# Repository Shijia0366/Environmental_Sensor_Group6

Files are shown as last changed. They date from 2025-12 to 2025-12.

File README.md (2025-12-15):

# Environmental Sensor Project - Group 6

This repository contains the complete design resources, source code, and measurement data for the Environmental Sensor project.

## Group Members
* Arno Liu
* Chengyu Yang
* Shijia Liu
* Zheyang Zheng

## Repository Structure

### 📂 Code
This folder contains the firmware source code. It includes two distinct sets of code:
* **Autonomous_Nodes_Environmental_Sensors:** Code developed for our self-fabricated sensor modules.
* **Commercial_Sensor:** Code tailored for the sensor provided by the department.

### 📂 Data
This folder contains real-world environmental data collected during field testing, organized chronologically by timestamp.
* **Calibration Note:** Please note that the first two data files contain **uncalibrated** raw data. All subsequent files contain **calibrated** data.
* **Note on ACC/PPG:** The `acc''ppg' dataset may show no readings due to system instability during the initial recording phase. However, the module was fully functional and successfully demonstrated during the final demo day.

### 📂 Enclosure
This folder stores all SolidWorks CAD files for the device housing.
* **Final Assembly:** The finalized 3D model is located in the file: `Enclosure design 3D Group 6 Final.SLDASM`.

### 📂 PCB
Contains the complete PCB design files used for the project.

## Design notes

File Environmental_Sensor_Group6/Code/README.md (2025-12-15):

#  MSc Sensor Systems Lab: Environmental Sensor Project - Group 6

##  Project Overview

* **Autonomous_Nodes_Environmental_Sensors:** Developed for the custom PCB (Task 1), utilizes the MAX30102 (PPG) for health data, the accelerometer is disabled due to hardware failure. Together with all environmental sensors.
* **Commercial_Sensor:** Developed for the department sensors nodes, utilizes the Pulse Sensor Amped (Green Light only) to capture Signal/BPM and the MPU-6050 (ACC) for motion data.
Both implementations are fully compatible with the Task 2 Environmental Sensor code and successfully perform environmental data acquisition.

## Group Members
| **Arno Liu** | |
| **Chengyu Yang** | |
| **Shijia Liu** | |
| **Zheyang Zheng** | |

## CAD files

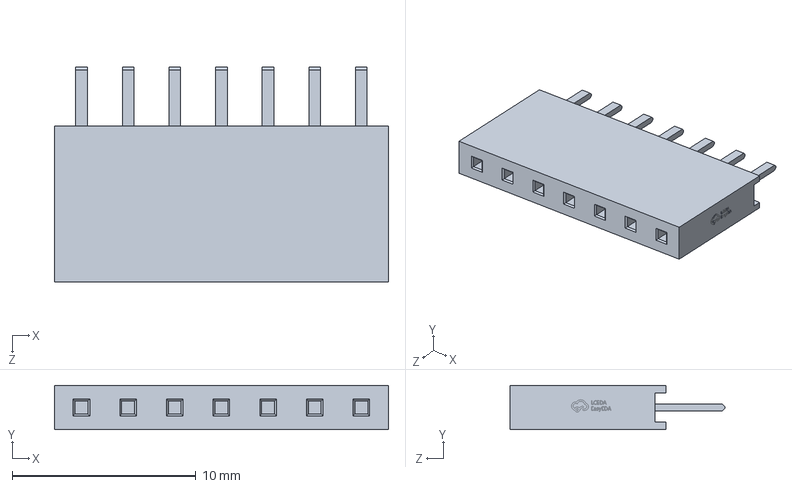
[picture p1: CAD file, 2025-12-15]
Environmental_Sensor_Group6/Enclosure/BME688~HDR-TH_7P-P2.54-V-F~HDR-TH_7P-P2.54-F-LI-1X7P~KTJj.SLDASM
18.2 x 2.40 x 11.7 mm

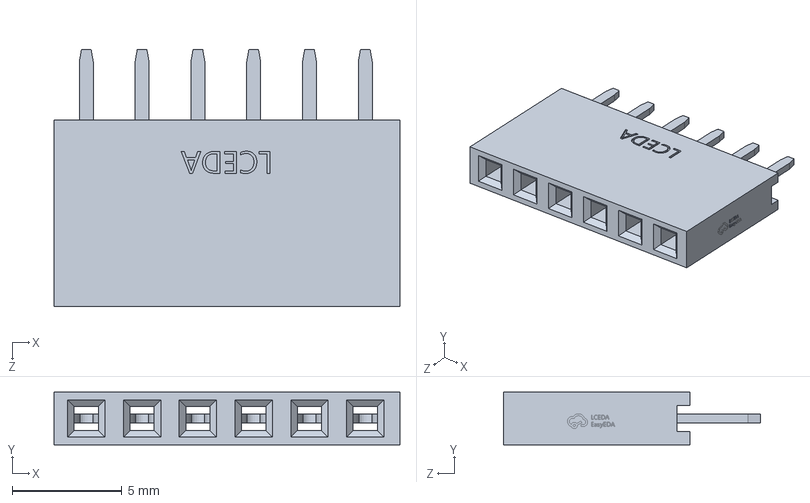
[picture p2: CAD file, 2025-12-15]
Environmental_Sensor_Group6/Enclosure/GPS1~HDR-TH_6P-P2.54-V-F~HDR-TH_6P-P2.54-V-F~KTJj.SLDASM
15.7 x 2.40 x 11.7 mm

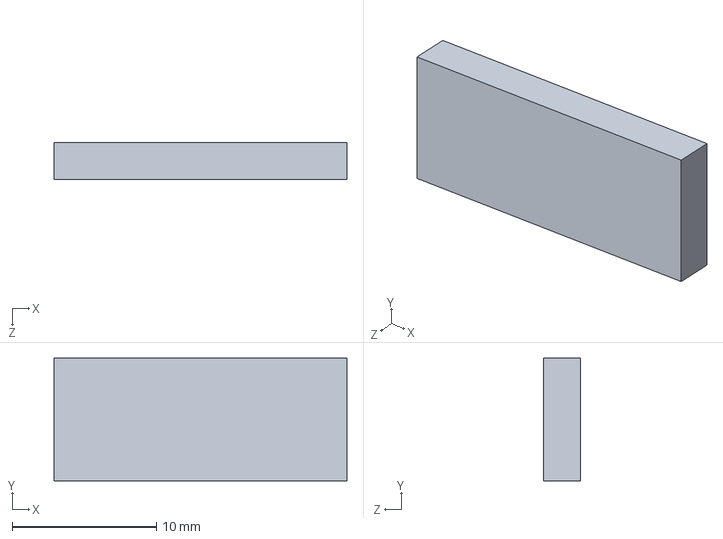
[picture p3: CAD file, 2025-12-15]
Environmental_Sensor_Group6/Enclosure/sd Socket.SLDPRT
20.3 x 8.50 x 2.54 mm

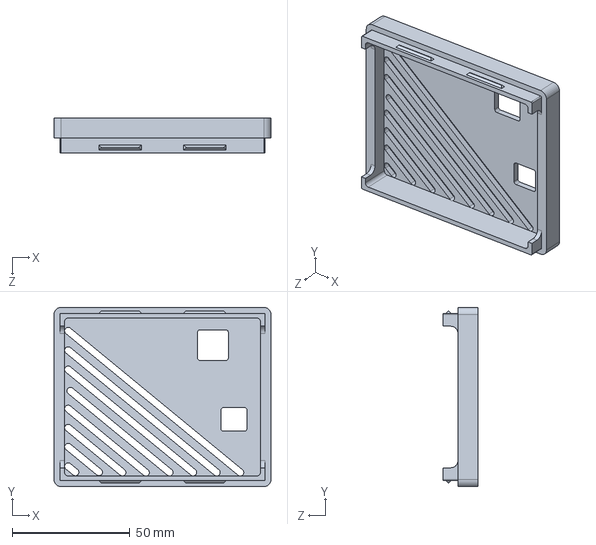
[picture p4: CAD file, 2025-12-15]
Environmental_Sensor_Group6/Enclosure/Cover.SLDPRT
92.0 x 76.0 x 14.8 mm

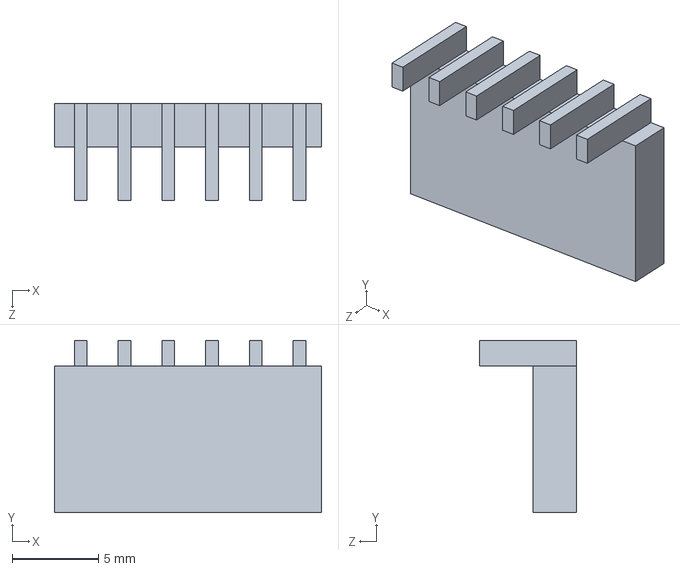
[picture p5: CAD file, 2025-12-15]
Environmental_Sensor_Group6/Enclosure/Right-Angle Female connector tof.SLDPRT
15.5 x 10.0 x 5.60 mm

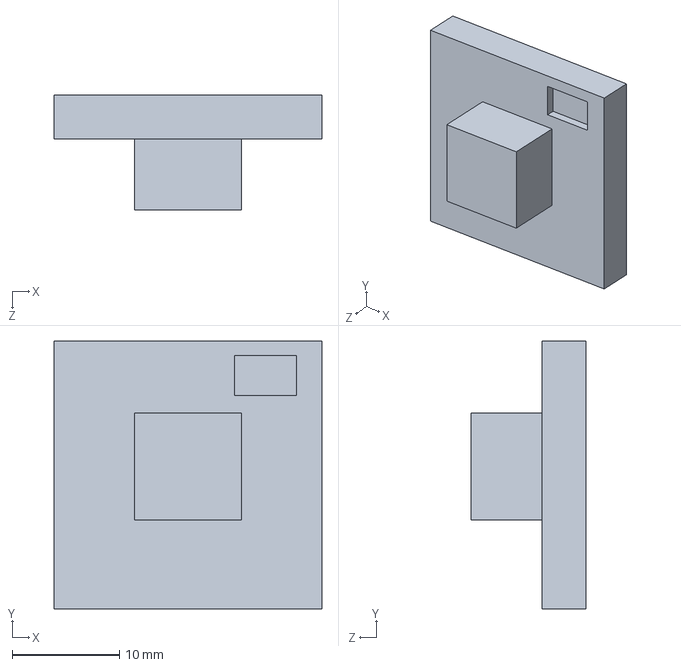
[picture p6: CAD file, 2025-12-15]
Environmental_Sensor_Group6/Enclosure/gps.SLDPRT
25.0 x 25.0 x 10.7 mm

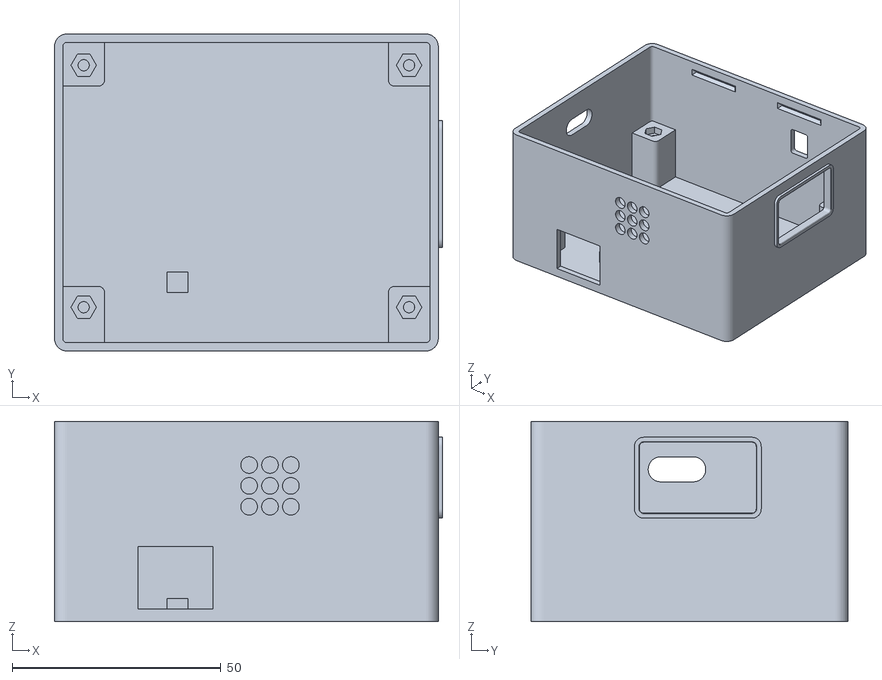
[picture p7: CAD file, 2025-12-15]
Environmental_Sensor_Group6/Enclosure/Enclosure design 3D Group 6 - Enclosure-1.STL
93.0 x 76.0 x 48.0

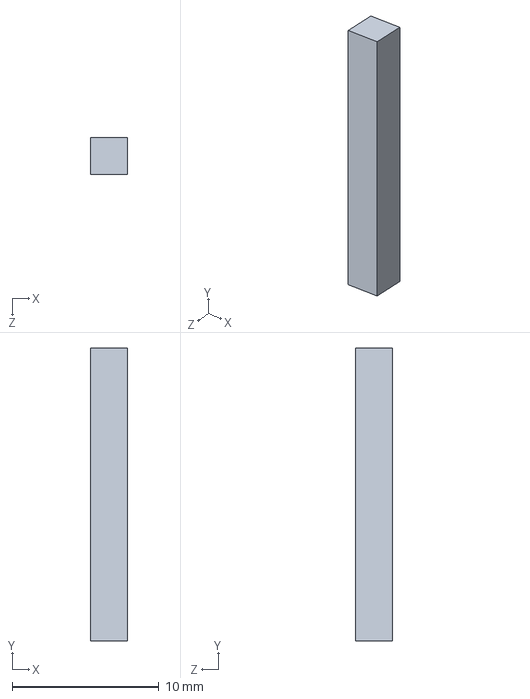
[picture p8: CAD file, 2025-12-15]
Environmental_Sensor_Group6/Enclosure/sd.SLDPRT
2.50 x 20.0 x 2.50 mm

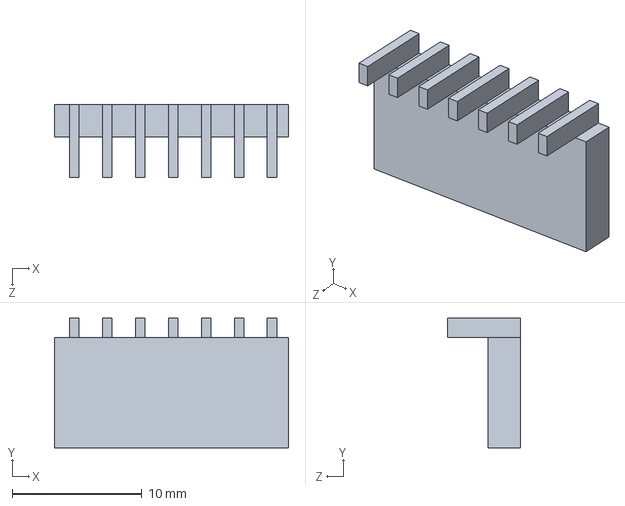
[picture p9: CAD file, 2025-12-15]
Environmental_Sensor_Group6/Enclosure/Right-Angle Female connector bme.SLDPRT
18.0 x 10.0 x 5.60 mm

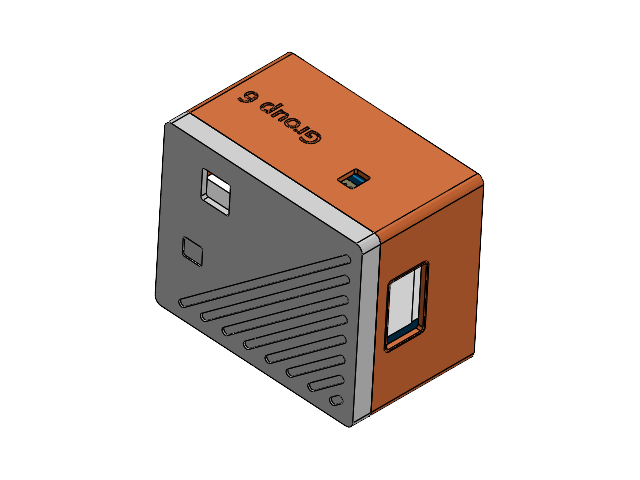
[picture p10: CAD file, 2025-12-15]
Environmental_Sensor_Group6/Enclosure/Environmental sensor pcb.SLDASM
HDR-TH_7P-P2.54-V-F~HDR-TH_7P-P2.54-F-LI-1X7P~KTJj x 2
HDR-TH_12P-P2.54-V-F~HDR-TH_12P-P2.54-F-LI-1X12P~KTJj
HDR-TH_6P-P2.54-V-F~HDR-TH_6P-P2.54-V-F~KTJj x 3
HDR-TH_16P-P2.54-V-F-1~HDR2.54-F-LI-1X16P~KTJj
RES-TH_BD2.7-L6.2-P10.20-D0.4~RES-TH_BD2.7-L6.2-P10.20-D0.4~KTJj x 2
Board~KTJj
TopSilkscreen~KTJj
BottomSilkscreen~KTJj
壳子
oled
esp32
弯母座
254.step
盖子
Board.step x 2
10uF.step x 4
AP2112K-3.3.step x 2
10K.step x 8
10K_1.step x 2
BSS138.step x 2
STEMMA_I2C_QT.step x 4
GREEN.step x 2
1N4148.step x 2
BME680.step x 2
弯母座bme
弯母座tof
按钮
gps

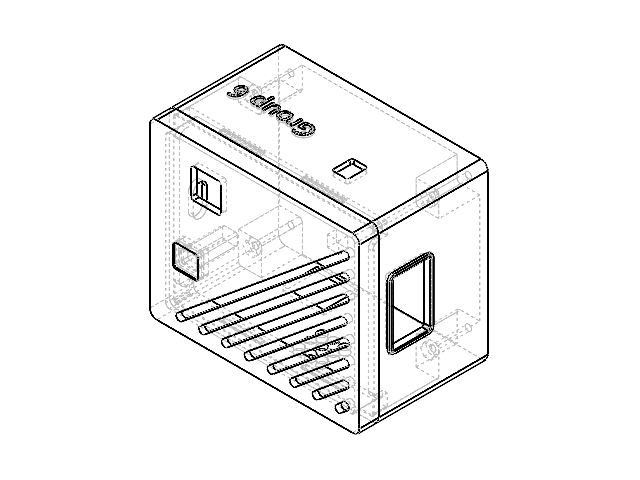
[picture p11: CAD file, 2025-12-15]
Environmental_Sensor_Group6/Enclosure/Enclosure design 3D Group 6 Final.SLDASM
Button
Cover
Enclosure
button fitting component

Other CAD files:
Environmental_Sensor_Group6/Enclosure/4MB Flash 2MB PSRAM~HDR-TH_16P-P2.54-V-F-1~HDR2.54-F-LI-1X16P~KTJj.SLDASM
Environmental_Sensor_Group6/Enclosure/ESP32 S3~HDR-TH_12P-P2.54-V-F~HDR-TH_12P-P2.54-F-LI-1X12P~KTJj.SLDASM
Environmental_Sensor_Group6/Enclosure/R2~RES-TH_BD2.7-L6.2-P10.20-D0.4~RES-TH_BD2.7-L6.2-P10.20-D0.4~KTJj.SLDASM
Environmental_Sensor_Group6/Enclosure/Board~KTJj.SLDPRT
Environmental_Sensor_Group6/Enclosure/Enclosure design 3D Group 6 - Cover-1.STL
Environmental_Sensor_Group6/Enclosure/HDR-TH_6P-P2.54-V-F~HDR-TH_6P-P2.54-V-F~KTJj.SLDPRT
Environmental_Sensor_Group6/Enclosure/HDR-TH_7P-P2.54-V-F~HDR-TH_7P-P2.54-F-LI-1X7P~KTJj.SLDPRT
Environmental_Sensor_Group6/Enclosure/BottomSilkscreen~KTJj.SLDPRT
Environmental_Sensor_Group6/Enclosure/Button.SLDPRT
Environmental_Sensor_Group6/Enclosure/Enclosure design 3D Group 6 - button fitting component-1.STL
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

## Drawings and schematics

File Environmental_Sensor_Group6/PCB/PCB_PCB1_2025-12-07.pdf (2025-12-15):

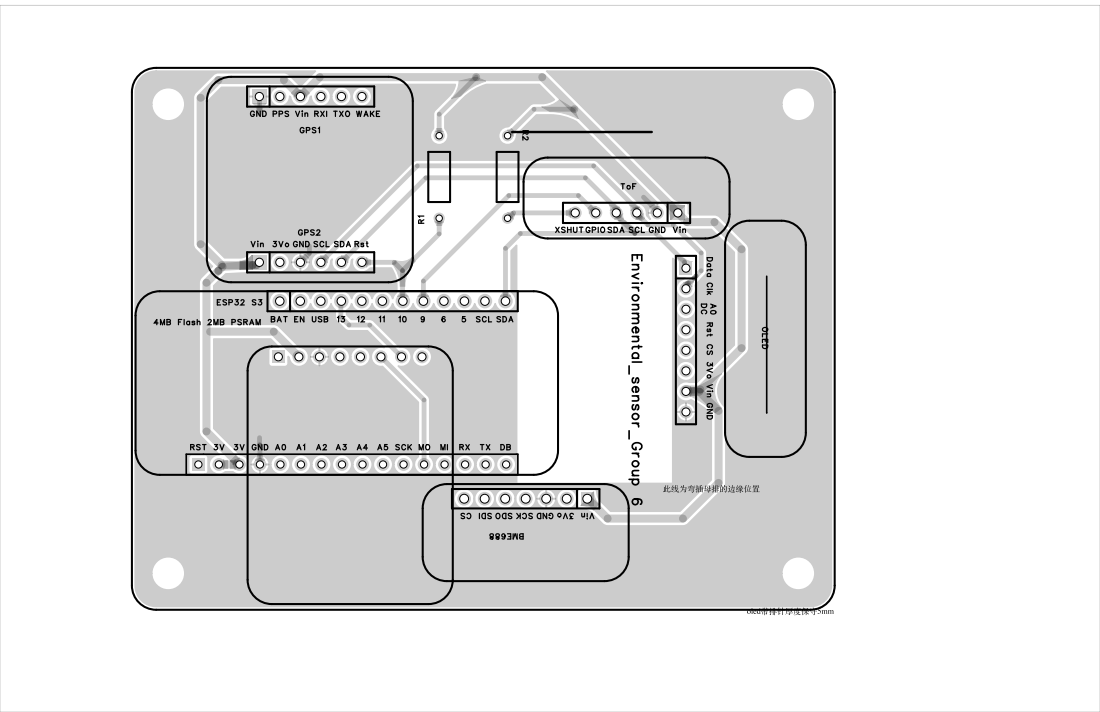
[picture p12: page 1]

GND
PPS Vin RXI TXO WAKE
GPS1

XSHUTGPIOSDA SCL GND Vin

Data Clk DCA0 Rst CS 3Vo Vin GND

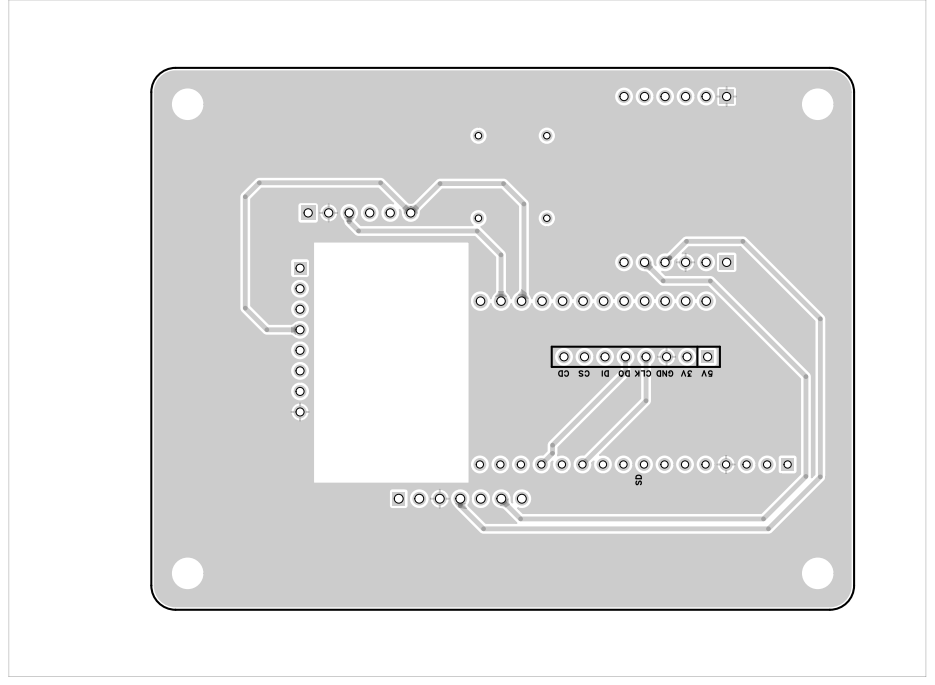
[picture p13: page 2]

CD CS DI DO CLK GND 3V 5V SD

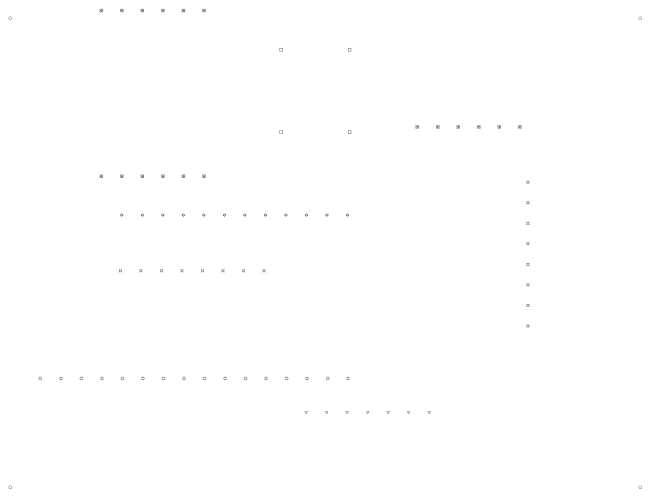
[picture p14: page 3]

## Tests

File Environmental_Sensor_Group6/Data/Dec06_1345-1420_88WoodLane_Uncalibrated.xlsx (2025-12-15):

timestamp_ms | temp_c | hum_pct | press_hpa | gas_ohm | AQI | dist_mm | speed | lat | lon | alt_m | fix | acc_x | acc_y | acc_z | ppg_red | ppg_ir
5046 | 16.19 | 59.7 | 996.5 | 7893 | 0 | 25 | nan | nan | nan | nan | 0 | nan | nan | nan | 0 | 0
10049 | 16.13 | 58.4 | 996.6 | 19565 | 0 | 31 | nan | nan | nan | nan | 0 | nan | nan | nan | 0 | 0
15031 | 16.27 | 57.5 | 996.6 | 29602 | 0 | 26 | nan | nan | nan | nan | 0 | nan | nan | nan | 0 | 0
20013 | 16.35 | 56.8 | 996.6 | 38988 | 0 | 25 | nan | nan | nan | nan | 0 | nan | nan | nan | 0 | 0
25006 | 16.37 | 56.1 | 996.6 | 48448 | 0 | 35 | nan | nan | nan | nan | 0 | nan | nan | nan | 0 | 0
30003 | 16.23 | 55.6 | 996.6 | 55077 | 0 | 37 | nan | nan | nan | nan | 0 | nan | nan | nan | 0 | 0
35007 | 16.22 | 55.3 | 996.6 | 61068 | 0 | 37 | nan | nan | nan | nan | 0 | nan | nan | nan | 0 | 0
40013 | 16.14 | 55.1 | 996.6 | 67121 | 0 | 37 | nan | nan | nan | nan | 0 | nan | nan | nan | 0 | 0
45018 | 16.06 | 55 | 996.6 | 72051 | 0 | 37 | nan | nan | nan | nan | 0 | nan | nan | nan | 0 | 0
50019 | 16.16 | 55 | 996.6 | 76099 | 0 | 38 | nan | nan | nan | nan | 0 | nan | nan | nan | 0 | 0
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

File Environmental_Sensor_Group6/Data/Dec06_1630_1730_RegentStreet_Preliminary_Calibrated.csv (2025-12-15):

timestamp_ms | temp_c | hum_pct | press_hpa | gas_ohm | AQI | dist_mm | speed | lat | lon | alt_m | fix | acc_x | acc_y | acc_z | ppg_red | ppg_ir
5053 | 19.59 | 54 | 998.2 | 5684 | 10 | 52 | nan | nan | nan | nan | 0 | nan | nan | nan | 0 | 0
10057 | 19.38 | 52.6 | 998.2 | 12688 | 10 | 19 | nan | nan | nan | nan | 0 | nan | nan | nan | 0 | 0
15041 | 19.34 | 51.8 | 998.3 | 19565 | 8 | 9 | nan | nan | nan | nan | 0 | nan | nan | nan | 0 | 0
20020 | 19.13 | 51.6 | 998.2 | 24975 | 7 | 41 | nan | nan | nan | nan | 0 | nan | nan | nan | 0 | 0
25038 | 19.18 | 51.9 | 998.2 | 31364 | 6 | 19 | nan | nan | nan | nan | 0 | nan | nan | nan | 0 | 0
30039 | 19.16 | 51.7 | 998.3 | 36488 | 5 | 14 | nan | nan | nan | nan | 0 | nan | nan | nan | 0 | 0
35045 | 19.11 | 51.5 | 998.3 | 40855 | 5 | 21 | nan | nan | nan | nan | 0 | nan | nan | nan | 0 | 0
40050 | 19.23 | 51.5 | 998.3 | 44614 | 5 | 10 | nan | nan | nan | nan | 0 | nan | nan | nan | 0 | 0
45055 | 19.21 | 51.3 | 998.3 | 49459 | 4 | 13 | nan | nan | nan | nan | 0 | nan | nan | nan | 0 | 0
50019 | 19.23 | 51.4 | 998.4 | 52117 | 4 | 45 | nan | nan | nan | nan | 0 | nan | nan | nan | 0 | 0
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

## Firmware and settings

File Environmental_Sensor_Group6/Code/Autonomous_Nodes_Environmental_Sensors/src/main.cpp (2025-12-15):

#include <Arduino.h>
#include "config.h"

// Diagnostic Mode
#if DIAG_MODE
void diag_setup();
void diag_loop();
void setup(){ diag_setup(); }
void loop() { diag_loop();  }

// Normal Application Mode
#else
void app_setup();
void app_loop();
void setup(){ app_setup(); }
void loop() { app_loop();  }
#endif

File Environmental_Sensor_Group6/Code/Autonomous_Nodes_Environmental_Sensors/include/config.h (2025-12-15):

#pragma once

/************ I2C  ************/
#define I2C_SDA_PIN            -1        
#define I2C_SCL_PIN            -1
#define I2C_FREQUENCY          400000    

// STEMMA/QT Power switch
#define PIN_I2C_POWER          7
#define I2C_POWER_DELAY_MS     50         
#define I2C_BUS_SETTLE_MS      100       

/************ SPI ************/

#define SPI_SCK_PIN            -1        
#define SPI_MISO_PIN           -1        
#define SPI_MOSI_PIN           -1        

/************ SD Card (SPI) ************/
#define SD_CS                  13        
#define SD_INIT_FREQ_HZ        400000    
#define SD_WORK_FREQ_HZ        20000000  
#define SD_POWER_DELAY_MS      10        

#define SD_CD_PIN              -1        
#define SD_CD_ACTIVE_LOW       1         
#define SD_CD_DEBOUNCE_MS      20

/************ Device I2C Addresses ************/
#define ToF_ADDR               0x29
#define GPS_ADDR               0x10      // according to your GPS module's actual address
#define BME_ADDR               0x77
#define OLED_ADDR              0x3D

/************ Device Control Pins ************/
#define OLED_RESET             5        // OLED RST
// #define OLED_RESET             -1        
#define TOF_XSHUT_PIN          5        
// #define TOF_XSHUT_PIN          -1       

#define TOF_INT_PIN     9      


/************ App Settings ************/
#define LOG_INTERVAL_MS        10      
#define CSV_FILE_PATH          "/logs/data.csv"
#define CSV_HEADER             "timestamp_ms,temp_c,hum_pct,press_hpa,gas_ohm,AQI,dist_mm,speed,lat,lon,alt_m,fix,acc_x,acc_y,acc_z,HR,SPO2"

#define DIAG_MODE 0   //1 = Enter diagnostic mode; 0 = Normal app mode

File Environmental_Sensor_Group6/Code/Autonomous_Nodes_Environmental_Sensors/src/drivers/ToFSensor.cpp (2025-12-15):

#include "ToFSensor.h"

Status ToFSensor::begin(TwoWire& w, uint8_t i2cAddr, int8_t xshutPin, int8_t intPin) {
  addr_  = i2cAddr;
  xshut_ = xshutPin;
  intPin_= intPin;

  // XSHUT Hardware Reset (Optional)
  hwReset_();

  // Dynamically create VL53L4CX, passing TwoWire and XSHUT
  if (tof_) { delete tof_; tof_ = nullptr; }
  tof_ = new VL53L4CX(&w, xshut_);

  // Power on sequence (as per standard flow)
  tof_->begin();
  tof_->VL53L4CX_Off();

  // Initialize Sensor with address
  if (tof_->InitSensor(addr_) != 0) {
    ready_ = false;
    return Status::Err("ToF InitSensor failed");
  }

  // Configure ranging parameters and mode
  if (!configureRanging_().ok) {
    ready_ = false;
    return Status::Err("ToF configure failed");
  }

  // Interrupt Setup: GPIO1 output data ready (Low Active)
  if (intPin_ >= 0) {
    // pinMode(intPin_, INPUT_PULLUP);   // Common default
    pinMode(intPin_, INPUT); 
    intFired_ = false;
    attachInterruptArg(intPin_, &ToFSensor::isrThunk_, this, FALLING);
  }

  ready_ = true;
  return Status::Ok();
}

Status ToFSensor::configureRanging_() {
  int st = 0;

  // Distance Mode: SHORT / MEDIUM / LONG
  st |= tof_->VL53L4CX_SetDistanceMode(VL53L4CX_DISTANCEMODE_MEDIUM);
  if (st) return Status::Err("ToF set distance mode failed");

  // Timing Budget (us)
  st |= tof_->VL53L4CX_SetMeasurementTimingBudgetMicroSeconds(TOF_TIMING_BUDGET_MS * 1000UL);
  if (st) return Status::Err("ToF set timing budget failed");

  // Continuous Ranging
  st |= tof_->VL53L4CX_StartMeasurement();
  if (st) return Status::Err("ToF start measurement failed");

  return Status::Ok();
}


void ToFSensor::hwReset_() {
  if (xshut_ < 0) return;
  pinMode(xshut_, OUTPUT);
  digitalWrite(xshut_, LOW);   // Power Off
  delay(2);                    // tRESET >= 1ms
  digitalWrite(xshut_, HIGH);  // Power On
  delay(5);                    // Power stabilization
}

// Interrupt ISR Thunk
void IRAM_ATTR ToFSensor::isrThunk_(void* arg) {
  reinterpret_cast<ToFSensor*>(arg)->onInt_();
}
void IRAM_ATTR ToFSensor::onInt_() {
  intFired_ = true;
}

Status ToFSensor::read(float& dist_mm) {
  if (!ready_) return Status::Err("ToF not initialized");

  // Check Data Ready: Prefer Interrupt flag, then Register polling
  uint32_t t0 = millis();
  while (true) {
    bool ready = false;

    if (intPin_ >= 0) {
      // INT Low or ISR fired means ready
      if (!digitalRead(intPin_) || intFired_) {
        ready = true;
        intFired_ = false; // Consume flag
      }
    } else {
      // Poll ULD data-ready
      uint8_t newReady = 0;
      int st = tof_->VL53L4CX_GetMeasurementDataReady(&newReady);
      if (st == 0 && newReady) ready = true;
    }

    if (ready) break;
    if (millis() - t0 > TOF_TIMEOUT_MS) return Status::Err("ToF timeout");
    
    delay(1); // Avoid busy loop
  }

  // Read Multi-Object Data (Taking object #0)
  VL53L4CX_MultiRangingData_t data;
  int st = tof_->VL53L4CX_GetMultiRangingData(&data);
  if (st != 0 || data.NumberOfObjectsFound < 1) {
    // Clear interrupt and proceed to next frame
    tof_->VL53L4CX_ClearInterruptAndStartMeasurement();
    return Status::Err("ToF invalid frame");
  }

  dist_mm = data.RangeData[0].RangeMilliMeter;

  // Clear interrupt and restart next frame (Crucial for Continuous mode)
  tof_->VL53L4CX_ClearInterruptAndStartMeasurement();

  return Status::Ok();
}

Status ToFSensor::stop() {
  if (!ready_) return Status::Err("ToF not initialized");
  tof_->VL53L4CX_StopMeasurement();
  if (intPin_ >= 0) detachInterrupt(intPin_);
  return Status::Ok();
}

Status ToFSensor::start() {
  if (!ready_) return Status::Err("ToF not initialized");
  if (intPin_ >= 0) {
    intFired_ = false;
    attachInterruptArg(intPin_, &ToFSensor::isrThunk_, this, FALLING);
  }
  int st = tof_->VL53L4CX_StartMeasurement();
  if (st != 0) return Status::Err("ToF restart failed");
  return Status::Ok();
}

// === Forwarding Implementation to match ST Examples ===
int ToFSensor::InitSensor(uint8_t newAddr) {
  if (!tof_) return -1;
  addr_ = newAddr;
  return tof_->InitSensor(addr_);
}

int ToFSensor::VL53L4CX_Off() {
  if (!tof_) return -1;
  tof_->VL53L4CX_Off();
  return 0;
}

int ToFSensor::VL53L4CX_StartMeasurement() {
  if (!tof_) return -1;
  return tof_->VL53L4CX_StartMeasurement();
}

int ToFSensor::VL53L4CX_StopMeasurement() {
  if (!tof_) return -1;
  return tof_->VL53L4CX_StopMeasurement();
}

int ToFSensor::VL53L4CX_ClearInterruptAndStartMeasurement() {
  if (!tof_) return -1;
  return tof_->VL53L4CX_ClearInterruptAndStartMeasurement();
}

int ToFSensor::VL53L4CX_GetMeasurementDataReady(uint8_t* isReady) {
  if (!tof_ || !isReady) return -1;
  return tof_->VL53L4CX_GetMeasurementDataReady(isReady);
}

int ToFSensor::VL53L4CX_GetMultiRangingData(VL53L4CX_MultiRangingData_t* data) {
  if (!tof_ || !data) return -1;
  return tof_->VL53L4CX_GetMultiRangingData(data);
}

// === Common Configuration (Optional) ===
int ToFSensor::VL53L4CX_SetDistanceMode(uint8_t mode) {
  if (!tof_) return -1;
  return tof_->VL53L4CX_SetDistanceMode(mode);
}

int ToFSensor::VL53L4CX_SetMeasurementTimingBudgetMicroSeconds(uint32_t us) {
  if (!tof_) return -1;
  return tof_->VL53L4CX_SetMeasurementTimingBudgetMicroSeconds(us);
}

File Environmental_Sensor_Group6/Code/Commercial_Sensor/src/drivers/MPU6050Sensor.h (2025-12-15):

#pragma once
#include <Arduino.h>
#include <Adafruit_MPU6050.h>
#include <Adafruit_Sensor.h>
#include "../models/Result.h"
#include "../hal/Buses.h"
#include "config.h"

#ifndef MPU_I2C_ADDR
  #define MPU_I2C_ADDR MPU6050_I2CADDR_DEFAULT
#endif
#ifndef MPU_ACCEL_RANGE
  #define MPU_ACCEL_RANGE MPU6050_RANGE_8_G
#endif
#ifndef MPU_GYRO_RANGE
  #define MPU_GYRO_RANGE MPU6050_RANGE_500_DEG
#endif
#ifndef MPU_FILTER_BW
  #define MPU_FILTER_BW MPU6050_BAND_5_HZ
#endif
#ifndef MPU_MIN_PERIOD_MS
  #define MPU_MIN_PERIOD_MS 20
#endif

class MPU6050Sensor {
public:
    struct MPUData {
        float ax, ay, az; // m/s^2
        float gx, gy, gz; // rad/s
        float temp;       // degC
    };

    Status begin(TwoWire& w, uint8_t addr = MPU_I2C_ADDR);
    Status read(MPUData& data);
    
    // Calibration function
    void calibrate(); 

    bool isReady() const { return ready_; }

private:
    Adafruit_MPU6050 mpu;
    bool ready_ = false;

    // Used to store deviation values
    float offset_ax_ = 0;
    float offset_ay_ = 0;
    float offset_az_ = 0;
    float offset_gx_ = 0;
    float offset_gy_ = 0;
    float offset_gz_ = 0;
};
